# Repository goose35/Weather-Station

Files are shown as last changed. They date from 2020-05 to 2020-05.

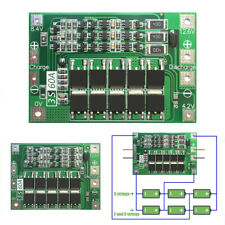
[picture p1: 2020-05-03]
BMS.jpg

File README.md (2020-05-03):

Personal Weather Station Project

A Weather station is a device that collects data related to the weather and environment using many different sensors. We can measure many things like: 
•	Temperature 
•	Humidity 
•	Wind 
•	Barometric Pressure 
•	UV index 
•	Rain
My inspiration to create this weather station came from this source along with the code which was modified to my purpose using Arduino Nano as main board and thing speak to send data to.

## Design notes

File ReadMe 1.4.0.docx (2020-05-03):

| 03/05/2020
| Weather Station Addendum This project is complete and Deployed in my yard However Due to the power consumption issues and size of batterry pack there are many improvements to be made Thus Revision 1.x versions will no longer be updated in favour of a rev 2.x (time permitting)

# Weather Station

# Weather Station

# Introduction

A Weather station is a device that collects data related to the weather and environment using many different sensors. We can measure many things like:

- Temperature
- Humidity
- Wind
- Barometric Pressure
- UV index
- Rain

My inspiration to create this weather station came from this source along with the code which was modified to my purpose using Arduino Nano as main board and thing speak to send data to.

https://www.instructables.com/id/Arduino-Uno-Wireless-Weather-Station-Wundergroundc/

ESP8266 WiFi module will send data to www.thingspeak.com

Thingspeak is a clous data collection service.

The following sensors were used:

Humidity, Pressure - BME280

UV, Solar - ML8511

Anenometer, wind directionand rain guage (3D printed)

## Power Supply

6x18650 cells will be used to power the project 3s2p and will be chard by solar during daytime hours. They fit inside the central control box with the PCB (see 3d Prints)

The original intent was to use 3x18650 in series to provide 12V but there are issues with power consumption and the battery life overnight.

Battery management is by ab 18650 BMS balance protection/charging board such as this


## Sensors

Temperature,Humidity and Barometric Pressure | Sparkfun BME280
UV index | ML8511
Wind Speed | Hall effect sensor and Magnet
Rain | Hall effect sensor and Magnet
Wind Direction | CJMCU-103 Angle Sensor

# 3D Printed Parts

STL files included for 3d printing.

Created by SeanTheITGuy on thingiverse

https://www.thingiverse.com/SeanTheITGuy/collections/arduino-weather-station

The Anemometer and Rain bucket use Hall effect sensors and magnets

The Wind vane uses CJMCU-103 Angle Sensor

Printer settings as follows:-

Material: PLA

Nozzle Dia: 0.4

Layer height: 0.2

Support: Use tree support where possible

Skirt: Yes

Infill: 33% or higher

# Schematic

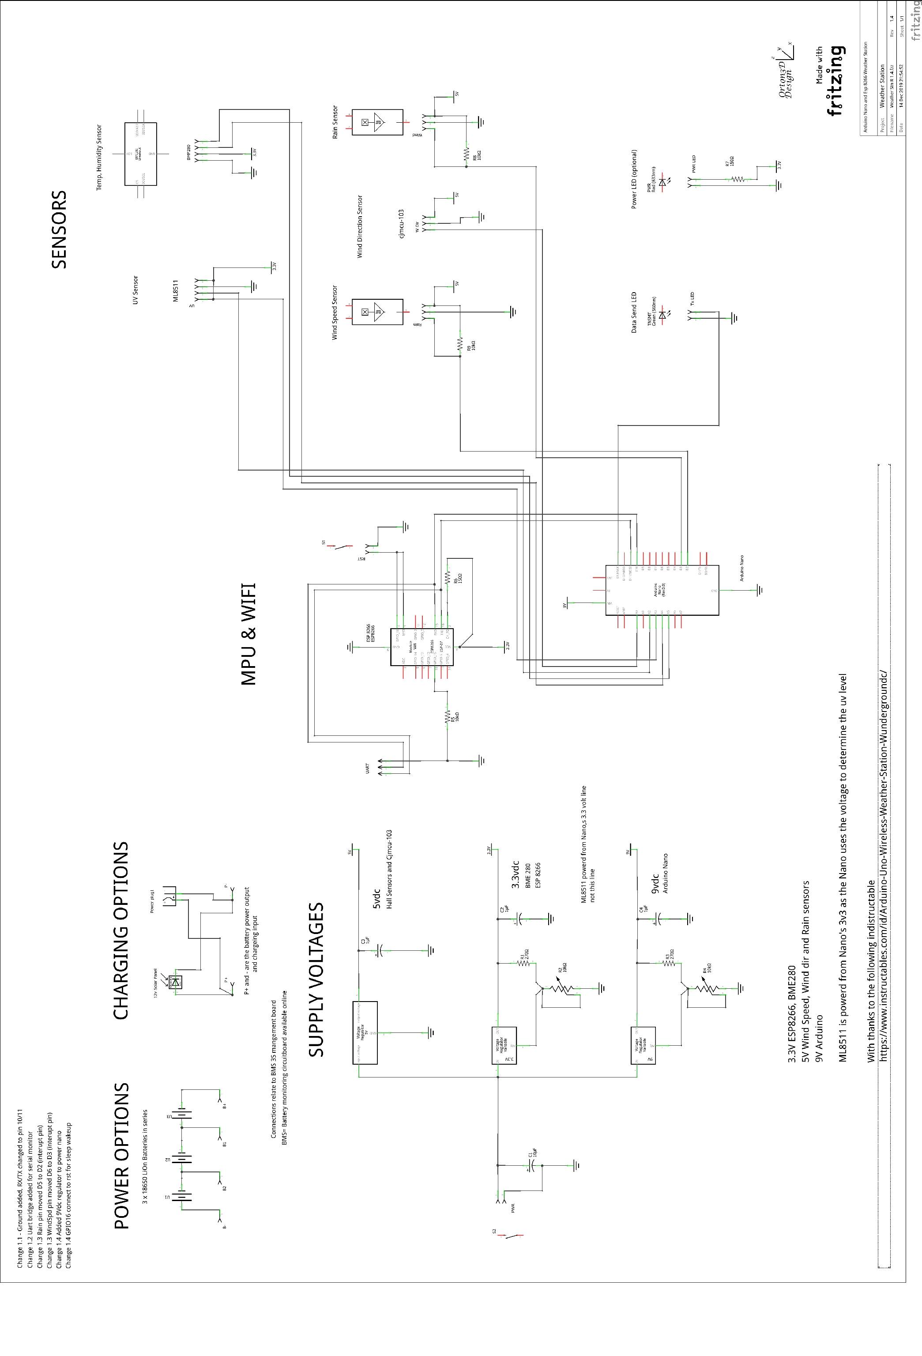
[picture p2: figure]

# PCB

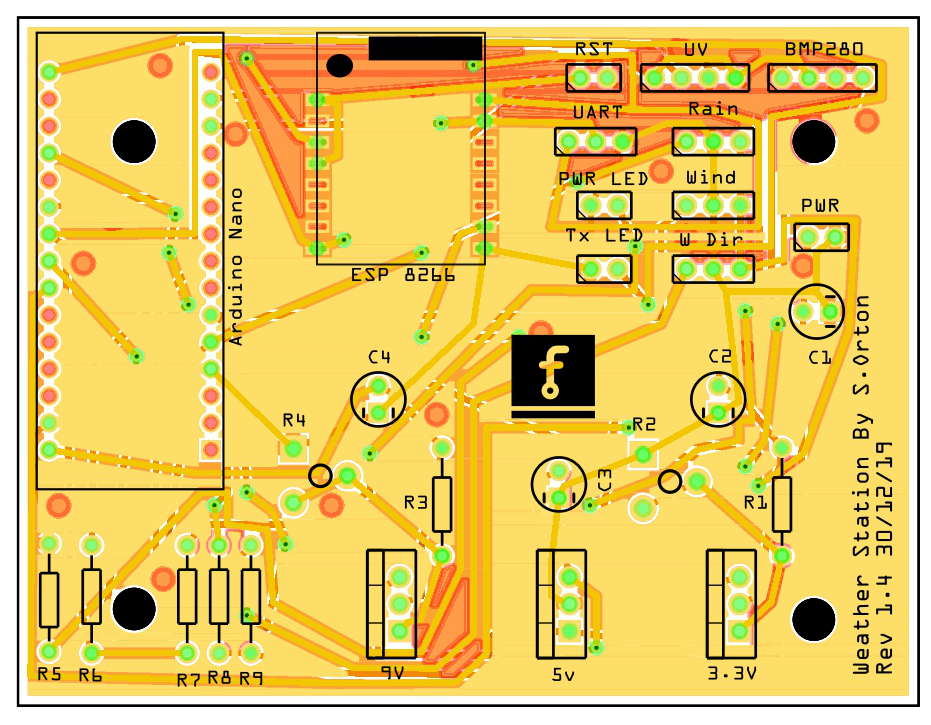
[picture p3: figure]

# BOM—Bill of Materials

## Assembly List

Label | Part Type | Properties
12v Solar Panel | SOLAR-IXYS | package solarbit-12x1; variant -
3.3V | Voltage Regulator - Variable | voltage Variable V; package TO220 [THT]
5v | Voltage Regulator - 5V | voltage 5V; package TO220 [THT]
9V | Voltage Regulator - Variable | voltage Variable V; package TO220 [THT]
Arduino Nano | Arduino Nano (Rev3.0) | type Arduino Nano (3.0)
B+ | Generic female header - 1 pins | pins 1; row single; form ♀ (female); package THT; hole size 1.0mm,0.508mm; pin spacing 0.1in (2.54mm)
B- | Generic female header - 1 pins | pins 1; row single; form ♀ (female); package THT; hole size 1.0mm,0.508mm; pin spacing 0.1in (2.54mm)
B1 | Generic female header - 1 pins | pins 1; row single; form ♀ (female); package THT; hole size 1.0mm,0.508mm; pin spacing 0.1in (2.54mm)
B2 | Generic female header - 1 pins | pins 1; row single; form ♀ (female); package THT; hole size 1.0mm,0.508mm; pin spacing 0.1in (2.54mm)
BMP280 | BME280 Breakout | power 3.3V; variant BME280
BMP280 | Generic female header - 4 pins | pins 4; row single; form ♀ (female); package THT; hole size 1.0mm,0.508mm; pin spacing 0.1in (2.54mm)
C1 | Electrolytic Capacitor | voltage 6.3V; package 100 mil [THT, electrolytic]; capacitance 10µF
C2 | Electrolytic Capacitor | voltage 6.3V; package 100 mil [THT, electrolytic]; capacitance 1µF
C3 | Electrolytic Capacitor | voltage 6.3V; package 100 mil [THT, electrolytic]; capacitance 1µF
C4 | Electrolytic Capacitor | voltage 6.3V; package 100 mil [THT, electrolytic]; capacitance 1µF
ESP 8266 | ESP8266 WiFi Module | variant variant 7; part # ESP8266
P+ | Generic female header - 1 pins | pins 1; row single; form ♀ (female); package THT; hole size 1.0mm,0.508mm; pin spacing 0.1in (2.54mm)
P- | Generic female header - 1 pins | pins 1; row single; form ♀ (female); package THT; hole size 1.0mm,0.508mm; pin spacing 0.1in (2.54mm)
Part2 | Schematic Frame | rev 1.4; descr Arduino Nano and Esp 8266 Weather Station; date 1576360492; project Weather Station; sheet 1/1; filename Weather Stn R 1.4.fzz
Power plug1 | Power plug
PWR | Red (633nm) LED | package 5 mm [THT]; color Red (633nm); leg yes
PWR | Generic female header - 2 pins | pins 2; row single; form ♀ (female); package THT; hole size 1.0mm,0.508mm; pin spacing 0.1in (2.54mm)
PWR LED | Generic female header - 2 pins | pins 2; row single; form ♀ (female); package THT; hole size 1.0mm,0.508mm; pin spacing 0.1in (2.54mm)
R1 | 270Ω Resistor | tolerance ±5%; resistance 270Ω; package THT; bands 4; pin spacing 400 mil
R2 | Trimmer Potentiometer | maximum resistance 10kΩ; package THT; type Trimmer Potentiometer; size Trimmer - 6mm; track Linear
R3 | 270Ω Resistor | tolerance ±5%; resistance 270Ω; package THT; bands 4; pin spacing 400 mil
R4 | Trimmer Potentiometer | maximum resistance 10kΩ; package THT; type Trimmer Potentiometer; size Trimmer - 6mm; track Linear
R5 | 10kΩ Resistor | tolerance ±5%; resistance 10kΩ; package THT; bands 4; pin spacing 400 mil
R6 | 150Ω Resistor | tolerance ±5%; resistance 150Ω; package THT; bands 4; pin spacing 400 mil
R7 | 150Ω Resistor | tolerance ±5%; resistance 150Ω; package THT; bands 4; pin spacing 400 mil
R8 | 10kΩ Resistor | tolerance ±5%; resistance 10kΩ; package THT; bands 4; pin spacing 400 mil
R9 | 10kΩ Resistor | tolerance ±5%; resistance 10kΩ; package THT; bands 4; pin spacing 400 mil
Rain | HALL-EFFECT | package sc70; variant smd
Rain | Generic female header - 3 pins | pins 3; row single; form ♀ (female); package THT; hole size 1.0mm,0.508mm; pin spacing 0.1in (2.54mm)
RST | Generic female header - 2 pins | pins 2; row single; form ♀ (female); package THT; hole size 1.0mm,0.508mm; pin spacing 0.1in (2.54mm)
S1 | Pushbutton | package THT; switching circuit SPST; default state Normally Open
S2 | Pushbutton | package THT; switching circuit SPST; default state Normally Open
TNSMT | Green (560nm) LED | package 5 mm [THT]; color Green (560nm); leg yes
Tx LED | Generic female header - 2 pins | pins 2; row single; form ♀ (female); package THT; hole size 1.0mm,0.508mm; pin spacing 0.1in (2.54mm)
U1 | LIPO-2000mAh | package lipo-2000; variant 2000mAh
U2 | LIPO-2000mAh | package lipo-2000; variant 2000mAh
U3 | LIPO-2000mAh | package lipo-2000; variant 2000mAh
UART | Generic male header - 3 pins | pins 3; row single; form ♂ (male); package THT; hole size 1.0mm,0.508mm; pin spacing 0.1in (2.54mm)
UV | Generic female header - 4 pins | pins 4; row single; form ♀ (female); package THT; hole size 1.0mm,0.508mm; pin spacing 0.1in (2.54mm)
W Dir | Generic female header - 3 pins | pins 3; row single; form ♀ (female); package THT; hole size 1.0mm,0.508mm; pin spacing 0.1in (2.54mm)
Wind | HALL-EFFECT | package sc70; variant smd
Wind | Generic female header - 3 pins | pins 3; row single; form ♀ (female); package THT; hole size 1.0mm,0.508mm; pin spacing 0.1in (2.54mm)

## Change Log

Date | Doc Rev. | Board Rev. | Change
03/05/2020 | 1.4.0 | 1.4 | First Document Issue

Page 1 of 6 Sch by https://www.allaboutcircuits.com/projects/diy-tools-build-your-own-logic-probe Board by RetroMakerGoose (retromakergoose@gmail.com)

Doc Rev. 1.4.0 Sunday, 03 May 2020

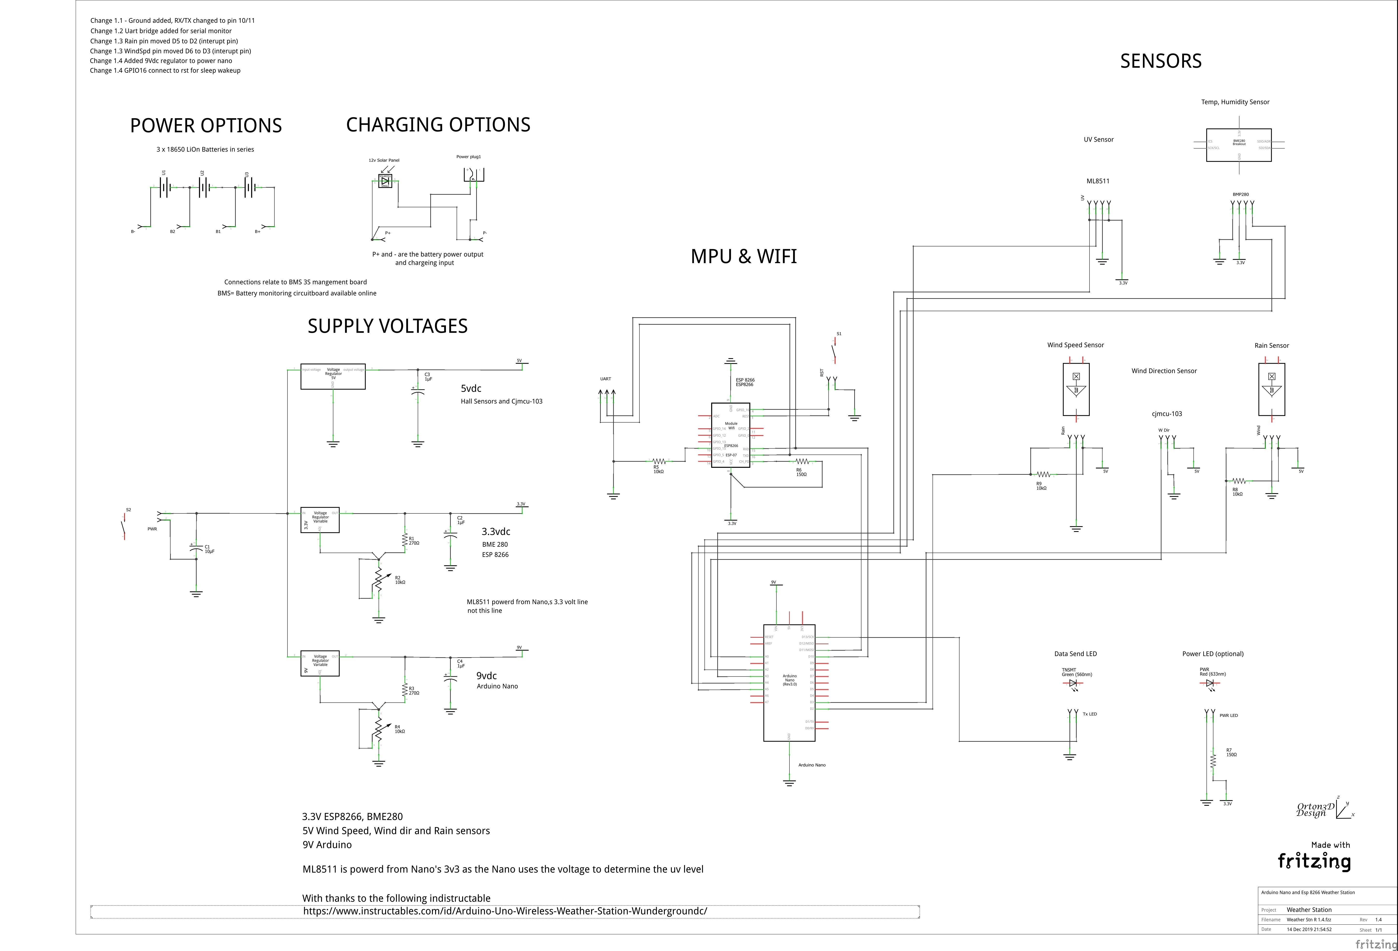
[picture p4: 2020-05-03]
Weather Stn R 1.4_schem.jpg

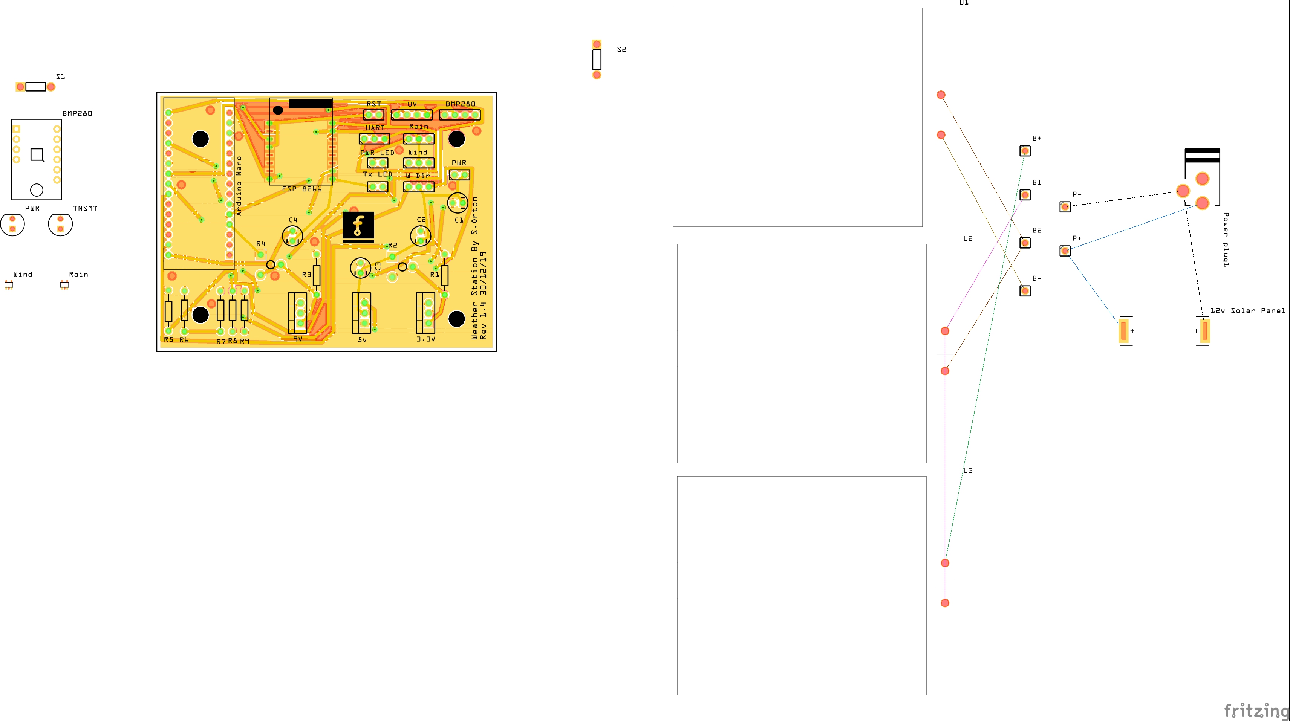
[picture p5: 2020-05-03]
Weather Stn R 1.4_pcb.jpg

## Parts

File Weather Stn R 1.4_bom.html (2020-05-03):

Label | Part Type | Properties
12v Solar Panel | SOLAR-IXYS | package solarbit-12x1; variant -
3.3V | Voltage Regulator - Variable | voltage Variable V; package TO220 [THT]
5v | Voltage Regulator - 5V | voltage 5V; package TO220 [THT]
9V | Voltage Regulator - Variable | voltage Variable V; package TO220 [THT]
Arduino Nano | Arduino Nano (Rev3.0) | type Arduino Nano (3.0)
B+ | Generic female header - 1 pins | pins 1; row single; form ♀ (female); package THT; hole size 1.0mm,0.508mm; pin spacing 0.1in (2.54mm)
B- | Generic female header - 1 pins | pins 1; row single; form ♀ (female); package THT; hole size 1.0mm,0.508mm; pin spacing 0.1in (2.54mm)
B1 | Generic female header - 1 pins | pins 1; row single; form ♀ (female); package THT; hole size 1.0mm,0.508mm; pin spacing 0.1in (2.54mm)
B2 | Generic female header - 1 pins | pins 1; row single; form ♀ (female); package THT; hole size 1.0mm,0.508mm; pin spacing 0.1in (2.54mm)
BMP280 | BME280 Breakout | power 3.3V; variant BME280
BMP280 | Generic female header - 4 pins | pins 4; row single; form ♀ (female); package THT; hole size 1.0mm,0.508mm; pin spacing 0.1in (2.54mm)
C1 | Electrolytic Capacitor | voltage 6.3V; package 100 mil [THT, electrolytic]; capacitance 10µF
C2 | Electrolytic Capacitor | voltage 6.3V; package 100 mil [THT, electrolytic]; capacitance 1µF
C3 | Electrolytic Capacitor | voltage 6.3V; package 100 mil [THT, electrolytic]; capacitance 1µF
C4 | Electrolytic Capacitor | voltage 6.3V; package 100 mil [THT, electrolytic]; capacitance 1µF
ESP 8266 | ESP8266 WiFi Module | variant variant 7; part # ESP8266
P+ | Generic female header - 1 pins | pins 1; row single; form ♀ (female); package THT; hole size 1.0mm,0.508mm; pin spacing 0.1in (2.54mm)
P- | Generic female header - 1 pins | pins 1; row single; form ♀ (female); package THT; hole size 1.0mm,0.508mm; pin spacing 0.1in (2.54mm)
Part2 | Schematic Frame | rev 1.4; descr Arduino Nano and Esp 8266 Weather Station; date 1576360492; project Weather Station; sheet 1/1; filename Weather Stn R 1.4.fzz
Power plug1 | Power plug
PWR | Red (633nm) LED | package 5 mm [THT]; color Red (633nm); leg yes
PWR | Generic female header - 2 pins | pins 2; row single; form ♀ (female); package THT; hole size 1.0mm,0.508mm; pin spacing 0.1in (2.54mm)
PWR LED | Generic female header - 2 pins | pins 2; row single; form ♀ (female); package THT; hole size 1.0mm,0.508mm; pin spacing 0.1in (2.54mm)
R1 | 270Ω Resistor | tolerance ±5%; resistance 270Ω; package THT; bands 4; pin spacing 400 mil
R2 | Trimmer Potentiometer | maximum resistance 10kΩ; package THT; type Trimmer Potentiometer; size Trimmer - 6mm; track Linear
R3 | 270Ω Resistor | tolerance ±5%; resistance 270Ω; package THT; bands 4; pin spacing 400 mil
R4 | Trimmer Potentiometer | maximum resistance 10kΩ; package THT; type Trimmer Potentiometer; size Trimmer - 6mm; track Linear
R5 | 10kΩ Resistor | tolerance ±5%; resistance 10kΩ; package THT; bands 4; pin spacing 400 mil
R6 | 150Ω Resistor | tolerance ±5%; resistance 150Ω; package THT; bands 4; pin spacing 400 mil
R7 | 150Ω Resistor | tolerance ±5%; resistance 150Ω; package THT; bands 4; pin spacing 400 mil
R8 | 10kΩ Resistor | tolerance ±5%; resistance 10kΩ; package THT; bands 4; pin spacing 400 mil
R9 | 10kΩ Resistor | tolerance ±5%; resistance 10kΩ; package THT; bands 4; pin spacing 400 mil
Rain | HALL-EFFECT | package sc70; variant smd
Rain | Generic female header - 3 pins | pins 3; row single; form ♀ (female); package THT; hole size 1.0mm,0.508mm; pin spacing 0.1in (2.54mm)
RST | Generic female header - 2 pins | pins 2; row single; form ♀ (female); package THT; hole size 1.0mm,0.508mm; pin spacing 0.1in (2.54mm)
S1 | Pushbutton | package THT; switching circuit SPST; default state Normally Open
S2 | Pushbutton | package THT; switching circuit SPST; default state Normally Open
TNSMT | Green (560nm) LED | package 5 mm [THT]; color Green (560nm); leg yes
Tx LED | Generic female header - 2 pins | pins 2; row single; form ♀ (female); package THT; hole size 1.0mm,0.508mm; pin spacing 0.1in (2.54mm)
U1 | LIPO-2000mAh | package lipo-2000; variant 2000mAh
U2 | LIPO-2000mAh | package lipo-2000; variant 2000mAh
U3 | LIPO-2000mAh | package lipo-2000; variant 2000mAh
UART | Generic male header - 3 pins | pins 3; row single; form ♂ (male); package THT; hole size 1.0mm,0.508mm; pin spacing 0.1in (2.54mm)
UV | Generic female header - 4 pins | pins 4; row single; form ♀ (female); package THT; hole size 1.0mm,0.508mm; pin spacing 0.1in (2.54mm)
W Dir | Generic female header - 3 pins | pins 3; row single; form ♀ (female); package THT; hole size 1.0mm,0.508mm; pin spacing 0.1in (2.54mm)
Wind | HALL-EFFECT | package sc70; variant smd
Wind | Generic female header - 3 pins | pins 3; row single; form ♀ (female); package THT; hole size 1.0mm,0.508mm; pin spacing 0.1in (2.54mm)
Amount | Part Type | Properties
1 | SOLAR-IXYS | package solarbit-12x1; variant -
2 | Voltage Regulator - Variable | voltage Variable V; package TO220 [THT]
1 | Voltage Regulator - 5V | voltage 5V; package TO220 [THT]
1 | Arduino Nano (Rev3.0) | type Arduino Nano (3.0)
6 | Generic female header - 1 pins | pins 1; row single; form ♀ (female); package THT; hole size 1.0mm,0.508mm; pin spacing 0.1in (2.54mm)
1 | BME280 Breakout | power 3.3V; variant BME280
2 | Generic female header - 4 pins | pins 4; row single; form ♀ (female); package THT; hole size 1.0mm,0.508mm; pin spacing 0.1in (2.54mm)
1 | Electrolytic Capacitor | voltage 6.3V; package 100 mil [THT, electrolytic]; capacitance 10µF
3 | Electrolytic Capacitor | voltage 6.3V; package 100 mil [THT, electrolytic]; capacitance 1µF
1 | ESP8266 WiFi Module | variant variant 7; part # ESP8266
1 | Schematic Frame | rev 1.4; descr Arduino Nano and Esp 8266 Weather Station; date 1576360492; project Weather Station; sheet 1/1; filename Weather Stn R 1.4.fzz
1 | Power plug
1 | Red (633nm) LED | package 5 mm [THT]; color Red (633nm); leg yes
4 | Generic female header - 2 pins | pins 2; row single; form ♀ (female); package THT; hole size 1.0mm,0.508mm; pin spacing 0.1in (2.54mm)
2 | 270Ω Resistor | tolerance ±5%; resistance 270Ω; package THT; bands 4; pin spacing 400 mil
2 | Trimmer Potentiometer | maximum resistance 10kΩ; package THT; type Trimmer Potentiometer; size Trimmer - 6mm; track Linear
3 | 10kΩ Resistor | tolerance ±5%; resistance 10kΩ; package THT; bands 4; pin spacing 400 mil
2 | 150Ω Resistor | tolerance ±5%; resistance 150Ω; package THT; bands 4; pin spacing 400 mil
2 | HALL-EFFECT | package sc70; variant smd
3 | Generic female header - 3 pins | pins 3; row single; form ♀ (female); package THT; hole size 1.0mm,0.508mm; pin spacing 0.1in (2.54mm)
2 | Pushbutton | package THT; switching circuit SPST; default state Normally Open
1 | Green (560nm) LED | package 5 mm [THT]; color Green (560nm); leg yes
3 | LIPO-2000mAh | package lipo-2000; variant 2000mAh
1 | Generic male header - 3 pins | pins 3; row single; form ♂ (male); package THT; hole size 1.0mm,0.508mm; pin spacing 0.1in (2.54mm)

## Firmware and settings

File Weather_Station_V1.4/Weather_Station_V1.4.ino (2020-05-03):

//Weather Station v1.4 Mod: S.Orton 11-01-2020
//Added UpdateInterval variable to set upload frequency
//Added if (counter == UpdateInterval) to counter function to vary upload frequency

#include <LowPower.h>
#include <Wire.h>
#include <SPI.h>
#include <Adafruit_Sensor.h>
#include <Adafruit_BME280.h>
#include <SoftwareSerial.h>
#include <LiquidCrystal.h>
#include <math.h>
#include "TimerOne.h"
#include <OneWire.h>
#include <stdlib.h>

#define Bucket_Size 0.02           // rain bucket size inches  ( 0.5mm)
#define GREEN_LED 13               //tx led
#define SEALEVELPRESSURE_HPA (1013.25)
#define WindSensorPin (3)          // The pin anemometer sensor is connected to
#define WindVanePin (A0)           // The pin the wind vane sensor is connected to
#define VaneOffset 0;              // Sensor offset from north 0-360
Adafruit_BME280 bme ;              // I2C  BME280 sensor
#define BME280_ADDRESS (0x76)      // SDO conect to GND address 0x76 or  CSB +3.3V address 0x77  
#define RainSensorPin 2            // The pin rain sensor is connected to
#define ONE_WIRE_BUS 4             // The pin temperature  DS18B20 sensor
#define DEBUG 0

volatile unsigned long tipCount1h;     // bucket tip counter used in interrupt routine
volatile unsigned long tipCount24h;    // bucket tip counter used in interrupt routine  
volatile unsigned long contactTime;    // Timer to manage any contact bounce in interrupt routine

volatile bool IsSampleRequired;       // this is set true every 2.5s. Get wind speed
volatile unsigned int  TimerCount;    // used to determine 2.5sec timer count for sampling
volatile unsigned long Rotations;     // cup rotation counter used in interrupt routine
volatile unsigned long ContactBounceTime;  // Timer to avoid contact bounce in interrupt routine

SoftwareSerial esp8266Module(10, 11); // RX, TX ESP8266
int UVOUT = A2; //Output from the sensor  UV Sensor
int REF_3V3 = A3; //3.3V power on the Arduino board UV Sensor
unsigned long delayTime;

int VaneValue;           // raw analog value from wind vane
int Direction;           // translated 0 - 360 direction
int CalDirection;        // converted value with offset applied
int LastValue;
float tempc;             // Temp celsius  BMP280
float tempc_min= 100;    // Minimum temperature C
float tempc_max;         // Maximum temperature C
float humidity;          // Humidity BMP280
float tempf=0;           // Temp farenheit BMP280
float dewptf=0;          // dew point tempc
float barompa;           // Preasure pascal Pa
float baromin;           // Preasure inches of mercury InHg
float baromhpa;          // Preasure hectopascal hPa
float refLevel;
float uvLevel;
float outputVoltage;
float uvIntensity = 0;   // UV 
float UVmax = 0;         // maximum UV intensity over the past 10 minutes
float altitudepws = 75.00;  //Local  altitude of the PWS to get relative pressure  meters (m)
float windSpeed;         // Wind speed (mph)
float wind_min = 100;     // Minimum wind speed (mph)
float wind_avg;          // 10 minutes average wind speed ( mph)
float windgustmph = 0;   // Maximum Wind gust speed( mph)
float rain1h = 0;        // Rain inches over the past hour
float rain24h = 0;       // Rain inches over the past 24 hours

unsigned int counter = 0;
unsigned int UpdateInterval = 10; //update data interval
unsigned int raincount1h = 0;
unsigned int raincount24h = 0;

//------------------------------------------------------------------------------------------------------------
//////////////////////////////////////////Network Details/////////////////////////////////////////////////////
//------------------------------------------------------------------------------------------------------------

String network = "VM4726600"; // your access point SSID
String password = "j7rRsHzwdpmb"; // your wifi Access Point password

#define IP "184.106.153.149" //thingspeak IP
String GET = "GET /update?key=A31I8HNRREF8X44G"; // API Key
/*
char server [] = "rtupdate.wunderground.com";        
char WEBPAGE [] = "GET /weatherstation/updateweatherstation.php?";
char ID [] = "IRUGEL1";        //wunderground weather station ID            
String PASSWORD  = "fBzDvfob";   // wunderground weather station password
*/
//------------------------------------------------------------------------------------------------------------
///////////////////////////////////////////////Main Program///////////////////////////////////////////////////
//------------------------------------------------------------------------------------------------------------

void setup() {
//set the clock prescaler
//CLKPR = 0x80;
//CLKPR = 0x02;

//esp8266Module.println(F("AT+SLEEP=1"));set esp 8266 sleep mode to light sleep

LastValue = 0;
IsSampleRequired = false;
TimerCount = 0;  // set TimerCount to 0 for interupts
tipCount1h = 0;
tipCount24h = 0;
{

Serial.begin(9600);
esp8266Module.begin(115200);
esp8266Module.println("AT+RST");
pinMode(UVOUT, INPUT);
pinMode(REF_3V3, INPUT);
pinMode(GREEN_LED,OUTPUT);
pinMode(RainSensorPin, INPUT);
pinMode(WindSensorPin, INPUT);
bme.begin(0x76);
Wire.begin();
delay(1000);
}

attachInterrupt(digitalPinToInterrupt(WindSensorPin), isr_rotation, FALLING); // Setup the wind timer intterupt
attachInterrupt(digitalPinToInterrupt(RainSensorPin), isr_rg, FALLING); // Setup the rain timer intterupt
Timer1.initialize(500000); // Timer interrupt every 0.5 seconds
Timer1.attachInterrupt(isr_timer);
sei();// Enable Interrupts
Serial.println("Start LovettSTN");
delay(3000);

}
  
void loop() {
read_data();    // read different sensors data from analog and digital pins of arduino
getWindSpeed();
isr_timer();
isr_rotation();
getRain();
getWindDirection();
updateData( float(tempc),  float(baromhpa),  float(humidity),  float(uvIntensity),  float(dewptf),  float(windSpeed),  int(Direction),  float(rain24h)); // sends data to thingspeak
if(DEBUG){
print_data();   // print in serial monitor
}
setupEsp8266();   //reset and connect esp
//LowPower.powerDown(SLEEP_8S, ADC_OFF, BOD_OFF);//(sleep arduino for 8 seconds

}

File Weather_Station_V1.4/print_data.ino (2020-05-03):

//------------------------------------------------------------------------------------------------------------
/////////////////////////////////PRINT DATA IN SERIAL MONITOR/////////////////////////////////////////////////
//------------------------------------------------------------------------------------------------------------
  
void print_data(void) 
 {
///////////////////////////////BME280////////////////////////////////
    Serial.print("Counter");
    Serial.println(counter);
    Serial.print(" ");
    Serial.print(F("BME280 = "));
    Serial.print("Temp = ");
    Serial.print(tempc);
    Serial.print(" C  ");
    Serial.print("Temp = ");
    Serial.print(tempf); 
    Serial.print(" F  ");
    Serial.print("Humidity = ");
    Serial.print(humidity); 
    Serial.print(" %  ");
    Serial.print("Pressure = ");
    Serial.print(baromhpa);
    Serial.print(" hPa  ");
    Serial.print("Pressure = ");
    Serial.print(baromin);
    Serial.print(" inHg  ");
    Serial.print(F("Approx altitude = "));
    Serial.print(bme.readAltitude(997.6)); // this should be adjusted to your local forcast http://www.mide.com/pages/air-pressure-at-altitude-calculator
    Serial.println(" m");
//////////////////////////////////////////UV///////////////////////////////////////////
    Serial.print("ML8511 = ");
    Serial.print("  UV = ");
    Serial.println(uvIntensity);
    Serial.print("output: ");
    Serial.println(refLevel);
    Serial.print("ML8511 output: ");
    Serial.println(uvLevel);
    Serial.print("ML8511 voltage: ");
    Serial.println(outputVoltage);
    Serial.print("UV Intensity: ");
    Serial.print(uvIntensity);
    Serial.println(" mW/cm^2 ");
//////////////////////////////////////Wind speed///////////////////////////////////////////
    Serial.print("WindSpeed = ");
    Serial.print(windSpeed);
    Serial.print(" mph  ");
    Serial.print(getKnots(windSpeed));
    Serial.print(" knots  ");
    Serial.print(getms(windSpeed));
    Serial.println(" m/s  ");
    Serial.print("Wind_min = ");  //Minimum wind speed
    Serial.print(wind_min);
    Serial.print(" mph ");
    Serial.print("WindAvg = "); //Average wind speed
    Serial.print(wind_avg);
    Serial.print(" mph ");
    Serial.print("WindGust = "); //Maximum wind gust speed
    Serial.print(windgustmph);
    Serial.println(" mph ");
////////////////////////////////////Wind Direction////////////////////////////////////////
    Serial.print("Wind_Direction = ");   
    getHeading(CalDirection);
    Serial.println(" ");
    ///////////////////////////////Wind Strngth Calc///////////////////////////////////////
    Serial.print("WindStrength = ");
    getWindStrength(windSpeed);
    ///////////////////////////////Rain///////////////////////////////////////////////
    Serial.print("Rain Tip Count = ");
    Serial.println(tipCount24h);
    Serial.print("Precip. Rate = ");
    Serial.print(rain1h); Serial.println(" in");
    Serial.print("Precip Accum. Total: ");
    Serial.print(rain24h); Serial.println(" in");
    
 }
